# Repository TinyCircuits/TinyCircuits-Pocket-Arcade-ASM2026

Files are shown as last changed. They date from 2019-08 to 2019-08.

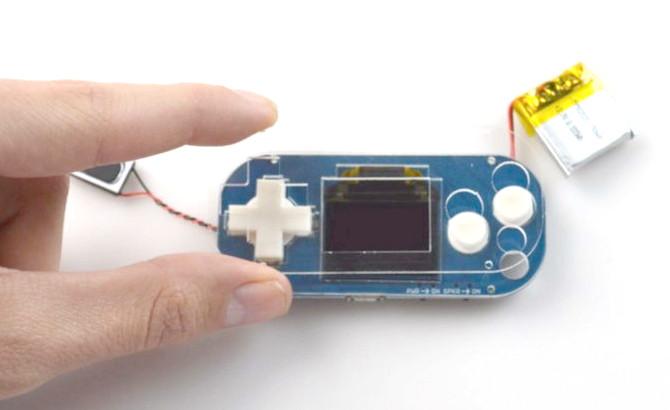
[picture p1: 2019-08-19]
images/Pocket-Arcade-Tutorial-Image-07.jpg

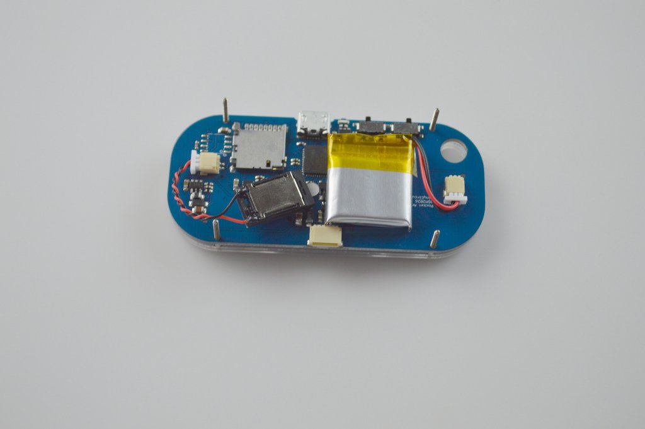
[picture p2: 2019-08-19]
images/Pocket-Arcade-Tutorial-Image-09.jpg

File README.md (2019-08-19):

# TinyCircuits Pocket Arcade
# ASM2026 Rev3

The design files are located under design_files/ for the TinyCircuits ASM2026 Rev 3 PCB. This is a tiny arcade game machine powered by Arduino software.

Format is in Cadsoft Eagle format - Eagle version 6.2 was used for the original design.

For more infomation on this, check out the product page at TinyCircuits.com: https://tinycircuits.com/collections/all/products/pocket-arcade

# License:

Design by TinyCircuits.
All design files are released under the Creative Commons Attribution Share-Alike 3.0 License, see the following link for details: http://creativecommons.org/licenses/by-sa/3.0

All text above must be included in any redistribution or derived design

This project uses designs and concepts developed as part of the Arduino project and the LilyPad project.  The TinyCircuits design files themselves (schematics, PCB and libraries) are not directly derived from these works' design files and have been created new, however the concepts and basic architecture behind the TinyDuino and TinyLily products are derived and we thank the hard work of the organizations below for their contributions to open-source hardware:
  
Original Arduino Uno Design by Team Arduino

LilyPad Arduino Design by Leah Buechley and Sparkfun Electronics

Please support the open-source hardware community

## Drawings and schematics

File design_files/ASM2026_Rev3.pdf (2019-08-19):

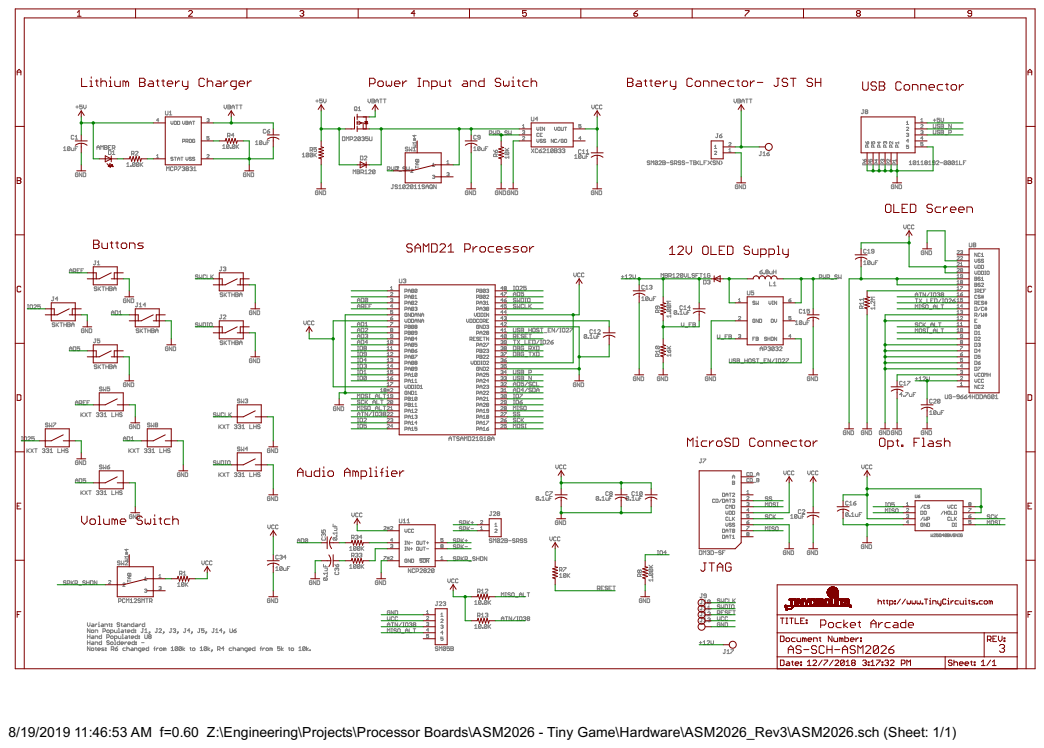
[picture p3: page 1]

8/19/2019 11:46:53 AM f=0.60 Z:\Engineering\Projects\Processor Boards\ASM2026 - Tiny Game\Hardware\ASM2026_Rev3\ASM2026.sch (Sheet: 1/1)

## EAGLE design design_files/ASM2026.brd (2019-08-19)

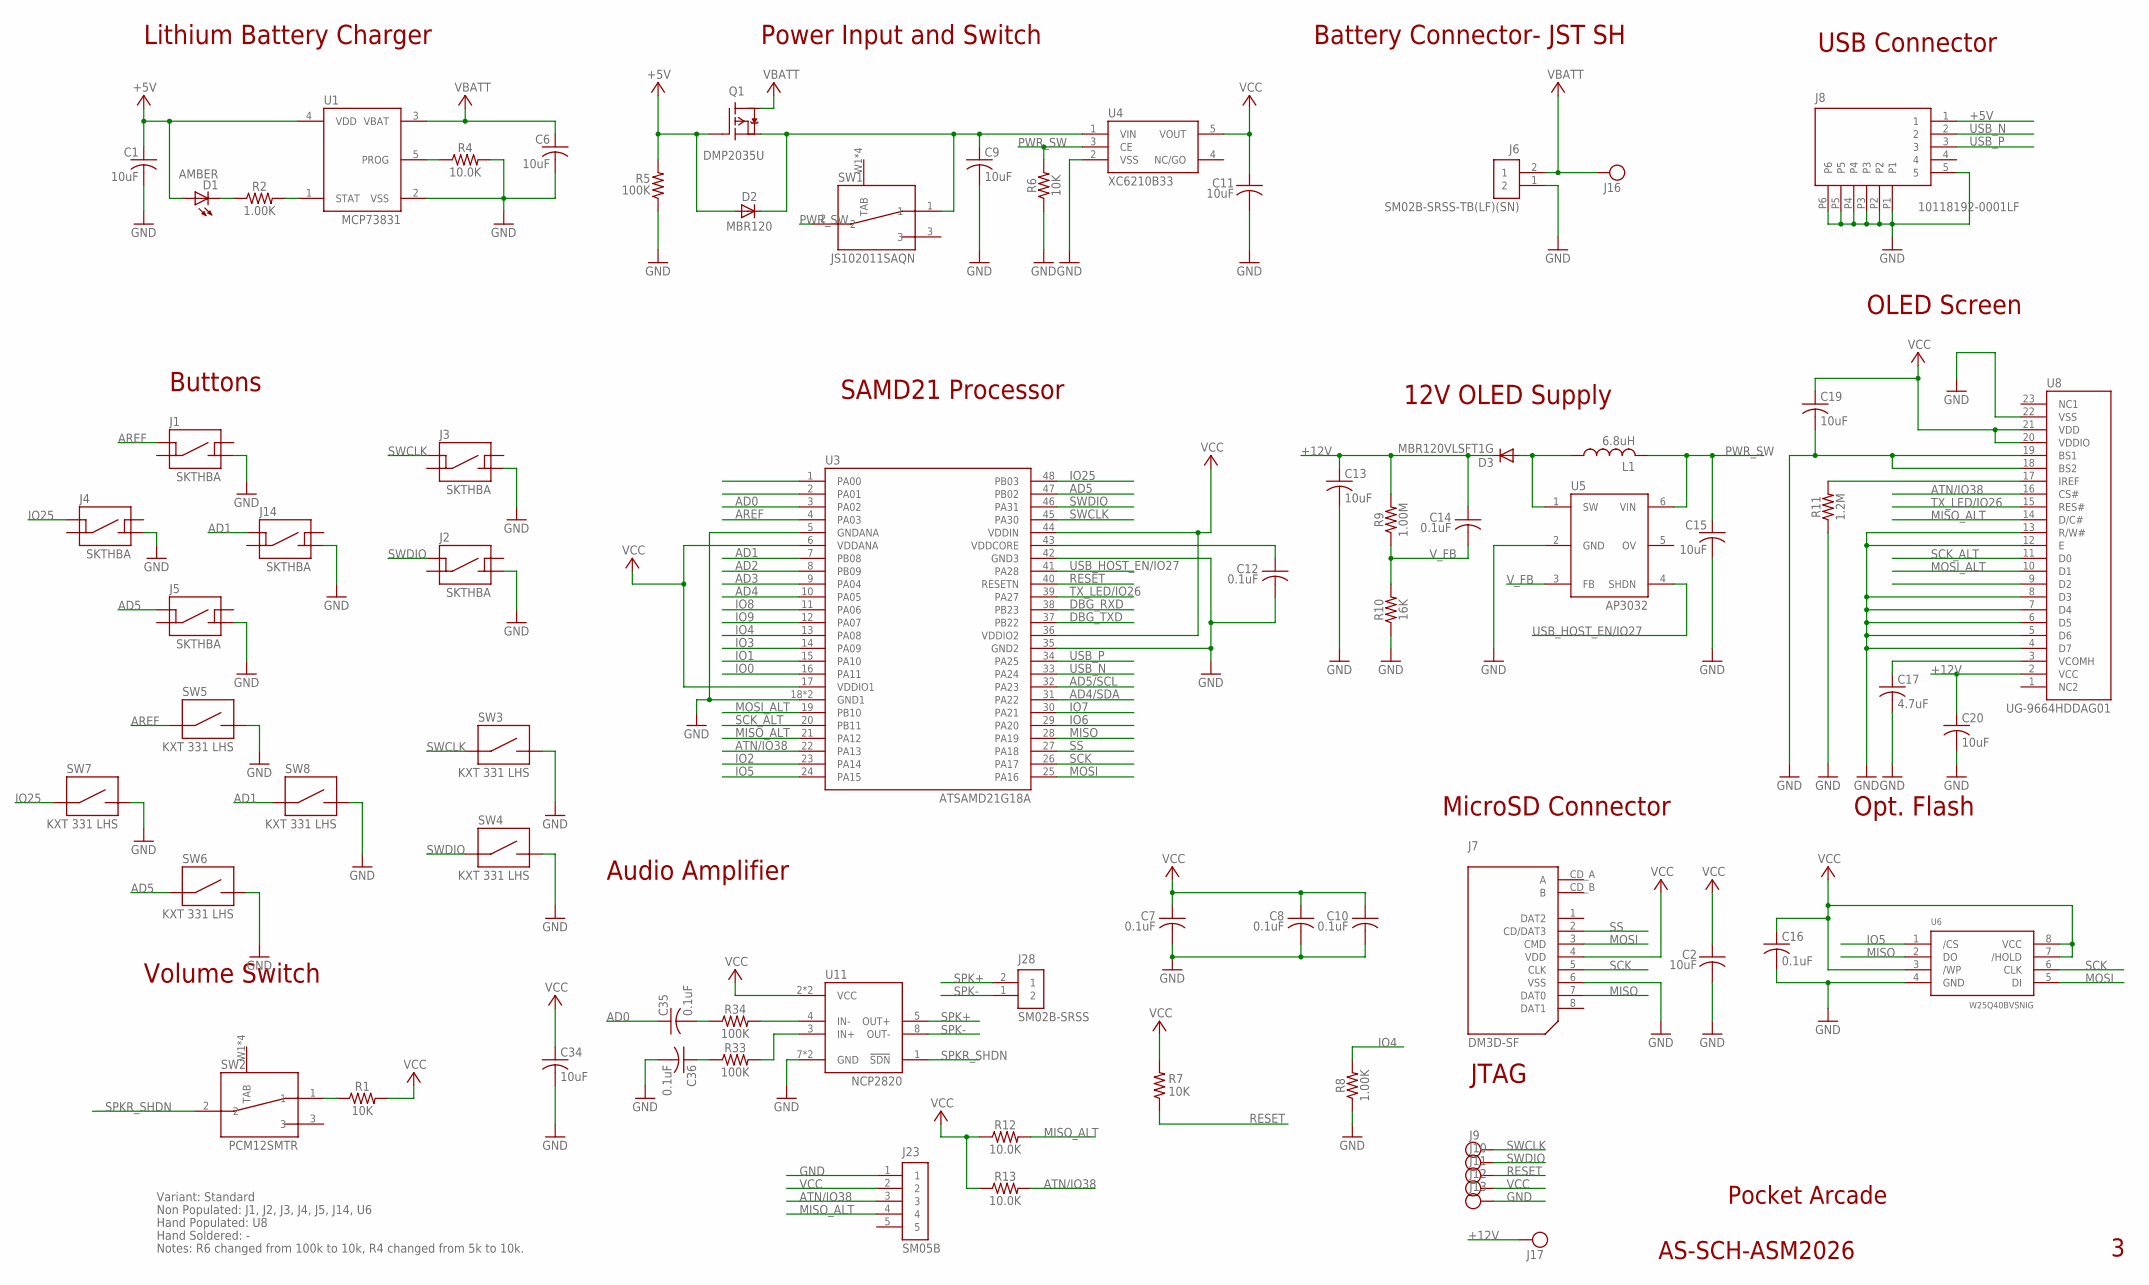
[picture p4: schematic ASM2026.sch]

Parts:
C1, C2, C6, C9, C11, C15, C34: 10uF; C0603; PARTNO AS-ITM-00002
C7, C8, C10, C12, C14: 0.1uF; C0402; PARTNO AS-ITM-00008
C13: 10uF; C0805; PARTNO AS-ITM-00045
C16, C35, C36: 0.1uF; C0402
C17: 4.7uF; 1206_CAP_TANT; PARTNO AS-ITM-00232
C19: 10uF; C0603
C20: 10uF; C0805
D1: AMBER; LNJ_LED; PARTNO AS-ITM-00026
D2: MBR120; SOD-123FL
D3: MBR120VLSFT1G; SOD-123FL
J1, J4, J5, J14: SKTHBA; SKTHBA_TACT; PARTNO AS-ITM-00369
J2, J3: SKTHBA; SKTHBA_TACT
J6: SM02B-SRSS-TB(LF)(SN); JST_SH_2X1
J7: DM3D-SF; SD_CARD
J8: 10118192-0001LF; MICRO_USB_ALT
J9, J10, J11, J12, J13, J16, J17: TEST_POINT; TEST_POINT_1MM
J23: SM05B; JST_SH_5X1
J28: SM02B-SRSS; JST_SH_2X1
L1: 6.8uH; R0805; PARTNO AS-ITM-00320
Q1: DMP2035U; SOT23A
R1, R6, R7: 10K; 0402; PARTNO AS-ITM-00032
R2, R8: 1.00K; 0402; PARTNO AS-ITM-00003
R4: 10.0K; 0402; PARTNO AS-ITM-00032
R5: 100K; 0402; PARTNO AS-ITM-00004
R9: 1.00M; 0402; PARTNO AS-ITM-00005
R10: 16K; 0402; PARTNO AS-ITM-00314
R11: 1.2M; 0402; PARTNO AS-ITM-00280
R12, R13: 10.0K; 0402
R33, R34: 100K; 0402
SW1: JS102011SAQN; PCM12SMTR; PARTNO AS-ITM-00220
SW2: PCM12SMTR
SW3, SW4, SW5, SW6, SW7, SW8: KXT 331 LHS; KXT_LHS_1
U1: MCP73831; SOT-23
U3: ATSAMD21G18A; QFN48; PARTNO AS-ITM-00273
U4: XC6210B33; SOT-25
U5: AP3032; SOT-23-6; PARTNO AS-ITM-00310
U6: W25Q40BVSNIG; 8-SOIC-N
U8: UG-9664HDDAG01; OLED_DISPLAY; PARTNO AS-ITM-00158
U11: NCP2820; WSON-8

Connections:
+5V: C1.1, D1.A, D2.A, J8.1, Q1.B (G), R5.2, U1.4 (VDD)
+12V: C13.1, C14.1, C20.1, D3.C, J17.P$1, R9.2, U8.2 (VCC)
AD0: C35.1, U3.3 (PA02)
AD1: J14.1, SW8.1, U3.7 (PB08)
AD2: U3.8 (PB09)
AD3: U3.9 (PA04)
AD4: U3.10 (PA05)
AD4/SDA: U3.31 (PA22)
AD5: J5.1, SW6.1, U3.47 (PB02)
AD5/SCL: U3.32 (PA23)
AREF: J1.1, SW5.1, U3.4 (PA03)
ATN/IO38: J23.3, R13.2, U3.22 (PA13), U8.16 (CS#)
DBG_RXD: U3.38 (PB23)
DBG_TXD: U3.37 (PB22)
GND: C1.2, C2.2, C6.2, C7.2, C8.2, C9.2, C10.2, C11.2, C12.2, C13.2, C15.2, C16.2, C17.2, C19.2, C20.2, C34.2, C36.2, J1.4, J2.4, J3.4, J4.4, J5.4, J6.1 (2), J7.6 (VSS), J8.5, J8.P1, J8.P2, J8.P3, J8.P4, J8.P5, J8.P6, J13.P$1, J14.4, J23.1, R4.2, R5.1, R6.1, R8.1, R10.1, R11.1, SW3.2, SW4.2, SW5.2, SW6.2, SW7.2, SW8.2, U1.2 (VSS), U3.5 (GNDANA), U3.18 (GND1), U3.35 (GND2), U3.42 (GND3), U3.EXP (GND1), U4.2 (VSS), U5.2 (GND), U6.4 (GND), U8.4 (D7), U8.5 (D6), U8.6 (D5), U8.7 (D4), U8.8 (D3), U8.12 (E), U8.13 (R/W#), U8.18 (BS2), U8.19 (BS1), U8.22 (VSS), U11.7 (GND), U11.9 (GND)
IO0: U3.16 (PA11)
IO1: U3.15 (PA10)
IO2: U3.23 (PA14)
IO3: U3.14 (PA09)
IO4: R8.2, U3.13 (PA08)
IO5: U3.24 (PA15), U6.1 (/CS)
IO6: U3.29 (PA20)
IO7: U3.30 (PA21)
IO8: U3.11 (PA06)
IO9: U3.12 (PA07)
IO25: J4.1, SW7.1, U3.48 (PB03)
MISO: J7.7 (DAT0), U3.28 (PA19), U6.2 (DO)
MISO_ALT: J23.4, R12.2, U3.21 (PA12), U8.14 (D/C#)
MOSI: J7.3 (CMD), U3.25 (PA16), U6.5 (DI)
MOSI_ALT: U3.19 (PB10), U8.10 (D1)
unnamed: R1.1, SW2.1
unnamed: D1.C, R2.1
unnamed: R4.1, U1.5 (PROG)
unnamed: R2.2, U1.1 (STAT)
unnamed: C12.1, U3.43 (VDDCORE)
unnamed: R11.2, U8.17 (IREF)
unnamed: C17.1, U8.3 (VCOMH)
unnamed: D3.A, L1.1, U5.1 (SW)
unnamed: R33.2, U11.3 (IN+)
unnamed: R34.2, U11.4 (IN-)
unnamed: C35.2, R34.1
unnamed: C36.1, R33.1
PWR_SW: C15.1, L1.2, R6.2, SW1.2, U4.3 (CE), U5.6 (VIN)
PWR_SWITCH: C9.1, D2.C, Q1.E (S), SW1.1, U4.1 (VIN)
RESET: J11.P$1, R7.1, U3.40 (RESETN)
SCK: J7.5 (CLK), U3.26 (PA17), U6.6 (CLK)
SCK_ALT: U3.20 (PB11), U8.11 (D0)
SPK+: J28.2 (1), U11.5 (OUT+)
SPK-: J28.1 (2), U11.8 (OUT-)
SPKR_SHDN: SW2.2, U11.1 (!SDN)
SS: J7.2 (CD/DAT3), U3.27 (PA18)
SWCLK: J3.1, J9.P$1, SW3.1, U3.45 (PA30)
SWDIO: J2.1, J10.P$1, SW4.1, U3.46 (PA31)
TX_LED/IO26: U3.39 (PA27), U8.15 (RES#)
USB_HOST_EN/IO27: U3.41 (PA28), U5.4 (SHDN)
USB_N: J8.2, U3.33 (PA24)
USB_P: J8.3, U3.34 (PA25)
VBATT: C6.1, J6.2 (1), J16.P$1, Q1.C (D), U1.3 (VBAT)
VCC: C2.1, C7.1, C8.1, C10.1, C11.1, C16.1, C19.1, C34.1, J7.4 (VDD), J12.P$1, J23.2, R1.2, R7.2, R12.1, R13.1, U3.6 (VDDANA), U3.17 (VDDIO1), U3.36 (VDDIO2), U3.44 (VDDIN), U4.5 (VOUT), U6.3 (/WP), U6.7 (/HOLD), U6.8 (VCC), U8.20 (VDDIO), U8.21 (VDD), U11.2 (VCC), U11.6 (VCC)
V_FB: C14.2, R9.1, R10.2, U5.3 (FB)

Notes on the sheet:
SAMD21 Processor
Power Input and Switch
Pocket Arcade
AS-SCH-ASM2026
Lithium Battery Charger
Battery Connector- JST SH
USB Connector
JTAG
12V OLED Supply
Buttons
Audio Amplifier
MicroSD Connector
Volume Switch
Opt. Flash
Non Populated: J1, J2, J3, J4, J5, J14, U6
Hand Populated: U8
Hand Soldered: -
Variant: Standard
Notes: R6 changed from 100k to 10k, R4 changed from 5k to 10k.
OLED Screen

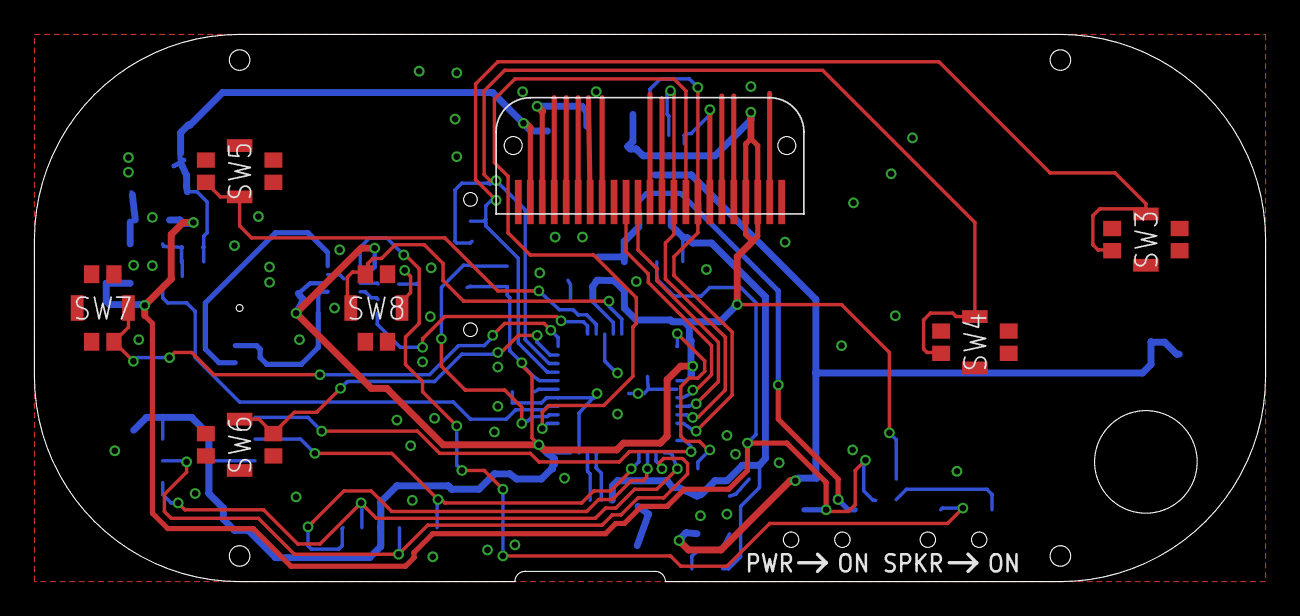
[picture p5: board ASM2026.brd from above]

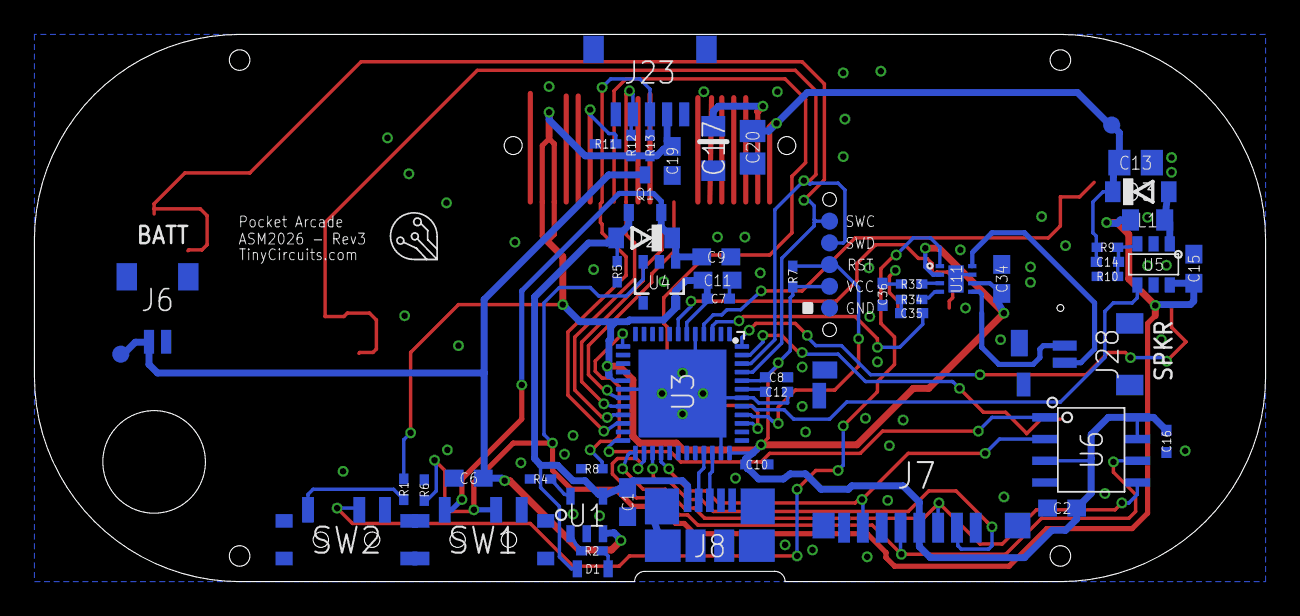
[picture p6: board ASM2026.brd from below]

Board: 2 copper layers, 72.0 x 32.0 mm, 72 parts (58 on the bottom side), 45 nets.

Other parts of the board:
U$1: DOCFIELD-TINYCIRCUITS-PCB

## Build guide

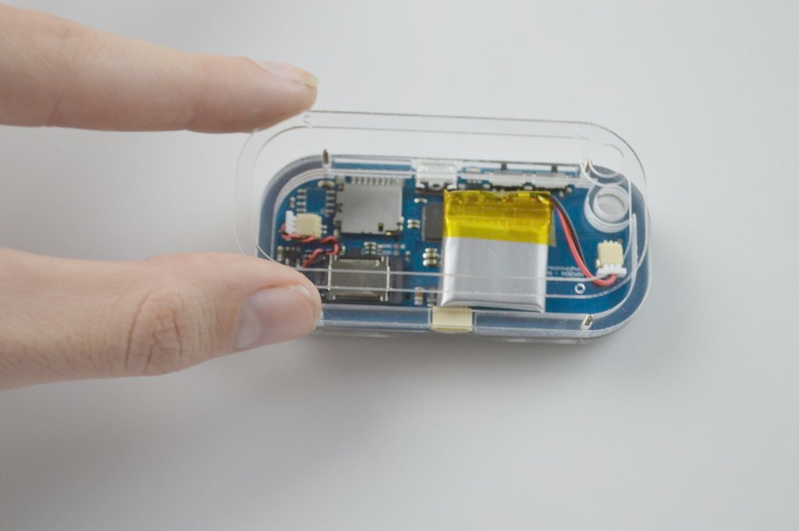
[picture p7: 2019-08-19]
images/Pocket-Arcade-Tutorial-Image-12.jpg

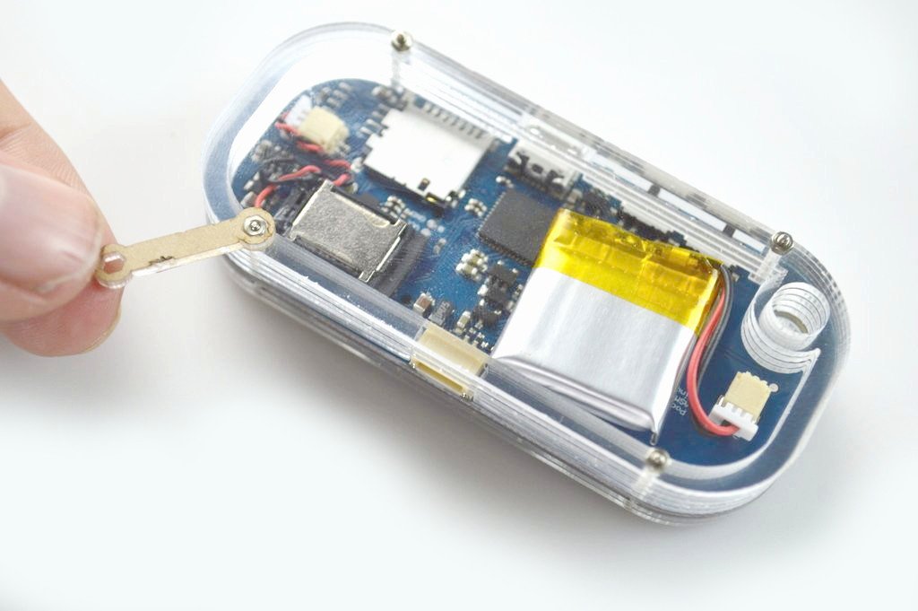
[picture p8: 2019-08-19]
images/Pocket-Arcade-Tutorial-Image-13.jpg

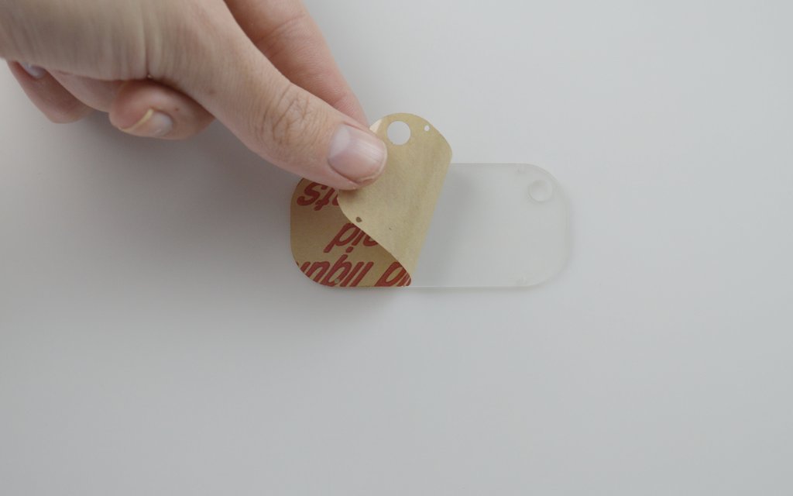
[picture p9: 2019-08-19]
images/Pocket-Arcade-Tutorial-Image-04.jpg

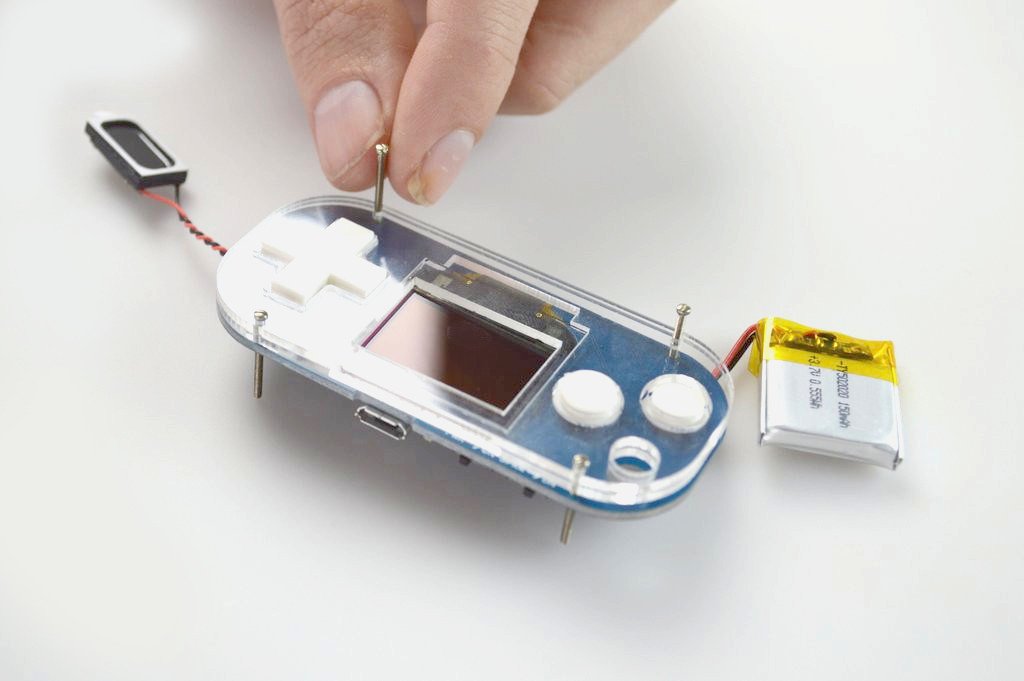
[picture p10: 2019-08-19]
images/Pocket-Arcade-Tutorial-Image-08.jpg
